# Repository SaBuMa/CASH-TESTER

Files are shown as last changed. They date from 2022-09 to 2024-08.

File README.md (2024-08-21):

# Proyecto Cash Tester

## Objetivos preliminares
* Implementar una solución viable a la problemática que más de 595.288 personas sufren en el país al no poder identificar eficazmente la denominación de las monedas de referencia __Colombiana.__ Desarrollando desde el campo de trabajo de la ingeniería una respuesta a una problemática latente, apostándole a la inclusión y al desarrollo del país.

* Implementar un sistema, con uso de la electrónica que generé una respuesta sonora, que una persona con baja visión/invidente reconozca a partir de la denominación de la moneda en vigencia.

## Descripción del Diseño
El proyecto se compone de un sensor (transductor) de resistencia sensible a la fuerza. La señal del transductor es acondicionada a través de un amplificador de instrumentación y un filtro pasa bajos.  
La señal proveniente del filtro es pasada por un detector de picos encargado de retardar el pico de voltaje el tiempo suficiente para que un circuito comparador la detecte, la clasifique y entregue un determinado voltaje DC al último circuito de la cadena que es un VCO (Voltage Controlled Oscillator).  
Por último, el VCO variará una alerta sonora en frecuencia para así de esta manera identificar el valor de la moneda.

## Descripción circuitos y Esquemáticos

* Un sensor (transductor) el cual es una resistencia sensible a la fuerza (FSR - FlexiForce A101).
* Circuito de acondicionamiento de señal usando un puente de wheatstone asi como también un amplificador de instrumentación y un filtro pasa bajos.

### Esquemático Circuito Amplificador y Circuito de filtrado

<p align="center">
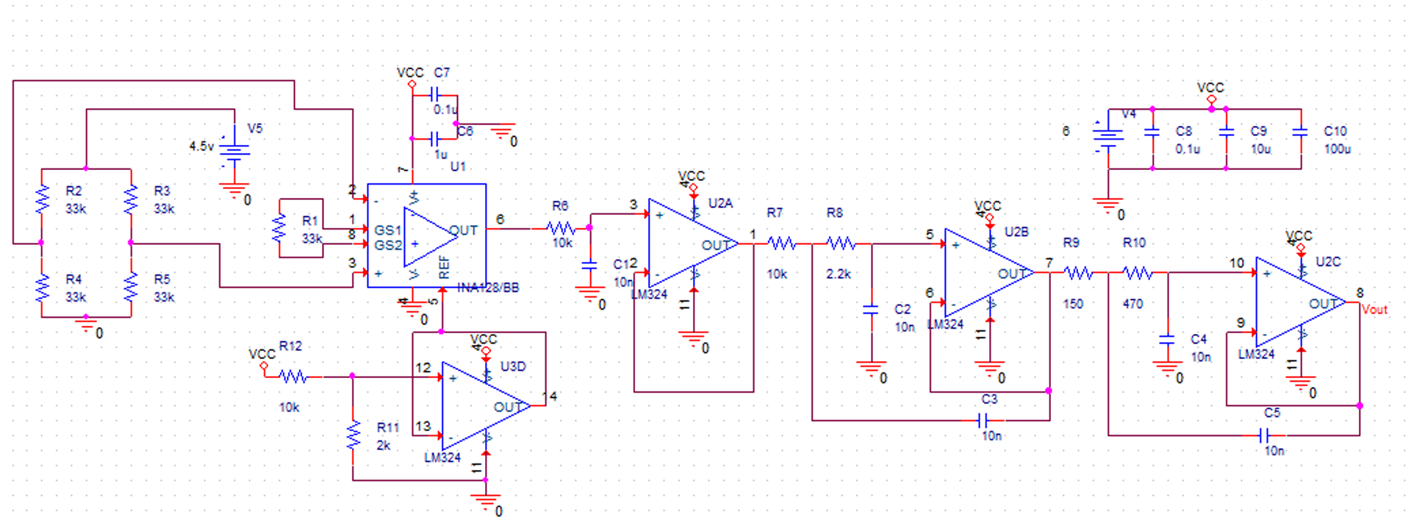
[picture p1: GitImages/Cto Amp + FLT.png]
Cto Amp + FLT
  
</p>

* La señal proveniente del filtro pasa bajos pasada por un circuito detector de picos el cual se encarga de retardar/ampliar la duración del pico de voltaje
* La señal proveniente del detector de picos es enviada a un comparador para clasificar y crear un voltaje DC.

### Esquemático Circuito Detector de picos y Circuito Comparador 
<p align="center">
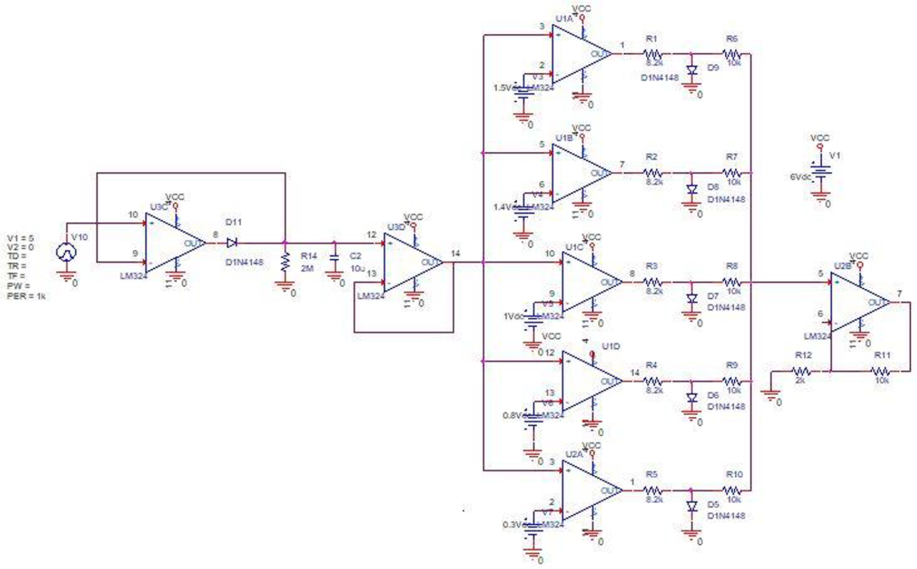
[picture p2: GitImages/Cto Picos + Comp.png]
Cto Picos + Comp
  
</p>

### Montaje en Protoboard para pruebas
<p align="center">
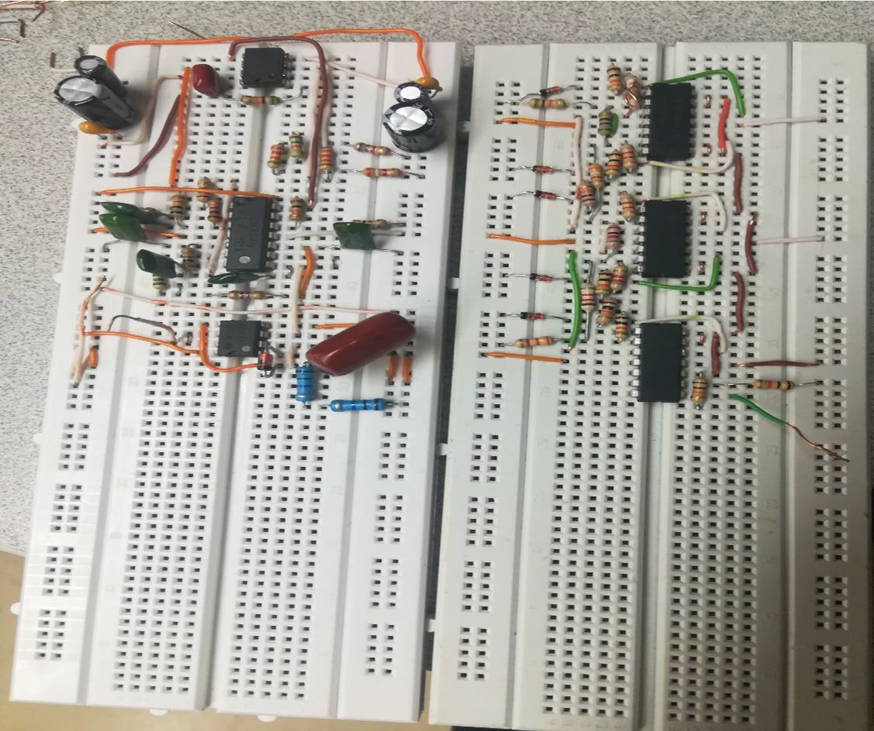
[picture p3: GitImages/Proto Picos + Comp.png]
Proto Picos + Comp
  
</p>

* El voltaje DC proveniente del comparador ingresa a un VCO el cual producirá una variación en frecuencia.  
* La frecuencia proveniente del VCO es usada para producir un sonido con el cual es posible identificar el valor de la moneda.

### PCB del Proyecto
<p align="center">
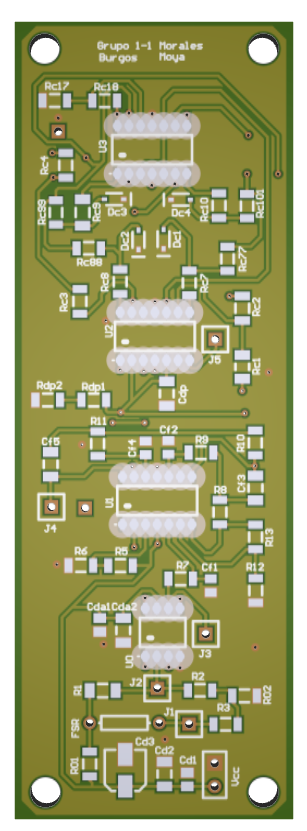
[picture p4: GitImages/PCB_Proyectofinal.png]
PCB_Proyectofinal
  
</p>

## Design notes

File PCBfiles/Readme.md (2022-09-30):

# En esta carpeta se encuentran los archivos de la pcb realizada en este proyecto

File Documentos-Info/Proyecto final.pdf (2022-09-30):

### DISEÑO FINAL: CASH TESTER

Andrea Camila Moya Buitrago
w.benavides@javeriana.edu.co

Natalia Morales Varón
nataliamorales@javeriana.edu.co

Santiago Burgos Martinez
santiagoburgos@javeriana.edu.co

Pontificia Universidad Javeriana

Bogotá, Colombia

INTRODUCCIÓN

En el presente informe del diseño final (cash tester), se analizará con detalle el proceso de concepción, diseño y construcción del proyecto que se llevó a cabo en la asignatura de fundamentos de diseño.

PALABRAS CLAVE

Amplificador instrumental, filtro pasa bajos, puente de Wheatstone, detector de picos, comparador, frecuencia, buzzer, invidentes.

OBJETIVO GENERAL

- Implementar una solución viable a la problemática que más de 595.288 personas sufren en el país al no poder identificar eficazmente la denominación de las monedas de referencia colombiana.

OBJETIVOS ESPECIFICOS

- Desarrollar desde el campo de trabajo de la ingeniería una respuesta a una problemática latente, apostándole a la inclusión y al desarrollo del país.
- Implementar un sistema, con uso de la electrónica que generé una respuesta sonora, que una persona con baja visión/invidente reconozca a partir de la denominación de la moneda en vigencia.

EQUIPO REQUERIDO

En la realización de la práctica se utilizaron los siguientes equipos:

- Generador de funciones - KEYSIGHT-33500

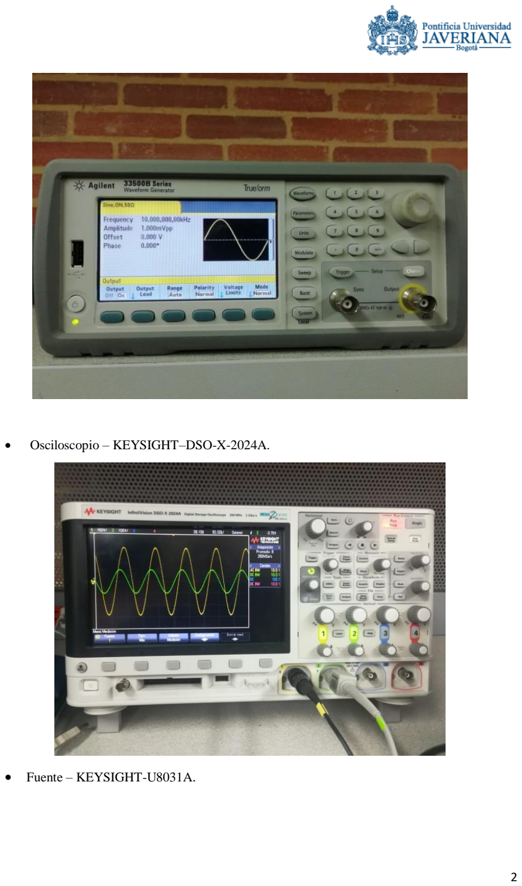
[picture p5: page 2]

- Osciloscopio – KEYSIGHT–DSO-X-2024A.
- Fuente – KEYSIGHT-U8031A.

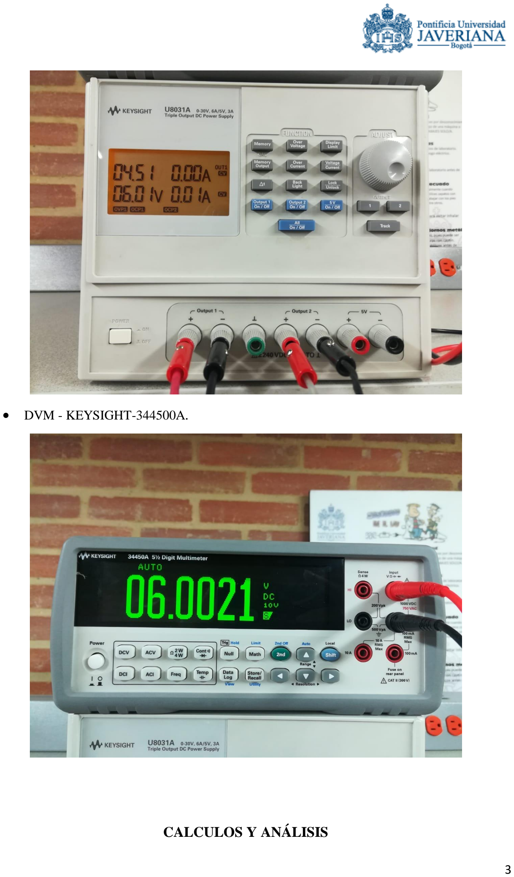
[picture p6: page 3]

- DVM - KEYSIGHT-344500A.

CALCULOS Y ANÁLISIS

El diseño se compone de un sensor (transductor) el cual es una resistencia sensible a la fuerza. Luego tenemos un acondicionamiento de señal que se compone de un amplificador de instrumentación y por un filtro pasa bajos, posteriormente la señal que sale del filtro es pasada por un detector de picos el cual se encarga de retardar el pico de voltaje lo necesario para que el comparador la detecte, la clasifique y entregue determinado voltaje DC al VCO que variará la frecuencia de un sonido para de esta manera identificar el valor de la moneda.

- Resistencia sensible a la fuerza (FSR)

FlexiForce A101

Para la realización de la practica utilizamos un sensor piezoeléctrico de fuerza ya que tiene un intervalo de medición de fuerza bastante grande y su diseño hace que sea cómodo para la idea principal que es la portabilidad.

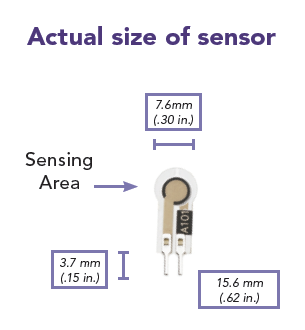
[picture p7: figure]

Fig 1. Sensor FlexiForce A101 y dimensiones

- Puente de Wheatstone

El puente de Wheatstone dentro de nuestro diseño cumple una función primordial ya que, de acuerdo con las especificaciones de nuestro sensor FSR (Force -Sensitive Resistor) escogido, este solo entrega una señal DC. De esta forma con la ayuda del puente de Wheatstone podemos obtener una señal diferencial la cual ya es posible que funcione de entrada a nuestro amplificador instrumental.

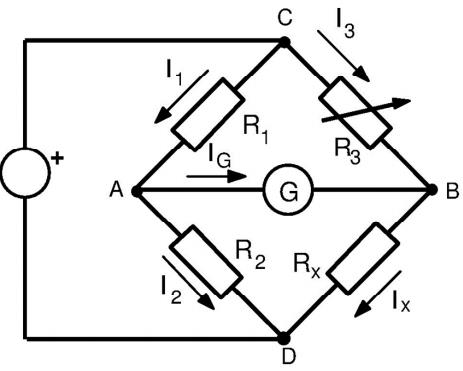
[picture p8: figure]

Fig2. Principio de funcionamiento de puente de Wheatstone. [1]

En efecto, cuando el puente está equilibrado sucede lo siguiente:

Ig = 0;I1 = I2;I3 = Ix; VA = VB

VCA

VAD

=

I1R1
I2R2

=

R1
R2

;

VCB

VBD

=

I3R3
IxRx

=

R3
Rx

VA = VB →

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
Luego, se obtiene que:

Rx = R3

R2
R1

Se puede demostrar que si se tiene un puente de Wheatstone equilibrado (IG = 0)

R1 = R2 = R3 = RX = R0.

Para determinar el valor de las resistencias del puente de Wheatstone que acompañan a nuestro sensor, partimos del datasheet de donde obtenemos la Fig 3. la cual nos dice que cuando el sensor no tiene fuerza aplicada sobre él, su resistencia máxima es de aproximadamente 32 KΩ.

Teniendo en cuenta esta resistencia máxima del sensor procedemos a buscar los valores comerciales de resistencias que se aproximen más a este valor para usarlas en el puente de Wheatstone. De la

búsqueda realizada encontramos que el valor más cercano a la resistencia del sensor es una resistencia de 33KΩ.

Por último, para la realización de simulaciones se opta por un valor base de 33k para el sensor dentro de nuestro puente de Wheatstone.

Fig 3. Grafica de Resistencia VS Presión (Fuerza) del sensor FlexiForce A101

ETAPA DE AMPLIFICACIÓN

- Amplificador de Instrumentación.

El amplificador de instrumentación tiene varias ventajas, una ganancia estable, lineal y seleccionable. Impedancia de entrada alta y una entrada diferencial con CMRR alto.

El esquemático en el cual está basado el amplificador instrumental es el siguiente

Fig 4. Esquemático amplificador instrumentación.

Etapa de pre-amplificación

Análisis

En el punto A:
VA − V1
RA

=

V1 − V2
RG

Despejamos VA

VA = V1 (

RA
RG

+ 1) −

RA
RG

V2

Ahora en el punto B:
V1 − V2
RG

=

V2 − VB
RB

Despejando VB

VB = V2 (

RB
RG

+ 1) −

RB
RG

V1

Si restamos ambas expresiones obtenemos

Vout = (V2 − V1

) (1 +
RA + RB
Rg

)

Nuestro paréntesis representa la ganancia diferencial de la etapa pre-amplificadora.

Etapa diferencial

Vout = (−

R2
R1

) VA (1 +

R2
R1

) ∗ (

R4
R3 + R4

) VB

TOTAL

Vd = VB − VA

Vcm =

VA + VB
2

Vout = −Vd [
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
)] + Vcm ∗ [
1 −

R2R3
R1R4

1 +

R3
R4

]

De donde se puede deducir lo siguiente

CMRR es cero sí 1 −

R2R3
R1R4

= 0. Esto si R2
R1

=

R4
R3

Además, se puede simplificar la ecuación si RA = RB

Ad =

R2
R1

(1 + 2
RA
Rg

)

La resistencia Rg permite variar la ganancia sin afectar el CMRR

Ahora, si nuestro terminal de Vref no se encuentra conectado a tierra, sino a otra tensión de referencia obtenemos entonces

Vout = Ad

(V

+ − V

−) + Vref

Por lo tanto:

Para la amplificación se tuvieron en cuenta dos amplificadores y se realizó una breve comparación con el fin escoger el más conveniente.

Amplificado r | Ganancia | CMRR | PSRR | Impedancia entrada | Impedanci a salida | BW | Slew Rate
LM324 | 100 V/mV | 70 típico | 100 típico | 12M | 58.3 | 1 MHz | 0.5 V/us
LM358 | 100 V/mV | 85 típico | 100 típico | 12 M | 58.3 | 1 MHz | 0.3 V/us

Tabla 1. Comparación entre amplificadores.

Observando la tabla podemos ver la diferencia existente en el CMRR y el slew rate. Teniendo en cuenta esta información obtenida de las hojas de especificaciones se puede deducir que el mejor LM358 es un mejor amplificador para esta aplicación.

De acuerdo a los requerimientos de la práctica, tenemos que sustituir los amplificadores previamente comparados por un amplificador de instrumentación. Ahora los requerimientos que tenemos para nuestro diseño son: un voltaje offset bajo tanto de entrada como de salida, un CMRR alto, la posibilidad de ser polarizado de forma single supply, tener una salida Rail to Rail.

Realizando una búsqueda intensiva de amplificadores de instrumentación en la página web de Texas Instruments (http://www.ti.com/amplifier-circuit/instrumentation/overview.html) buscando aquellos que cumplieran la mayoría de nuestros requisitos, como también estuvieran disponibles en el mercado colombiano reducimos nuestro resultado al amplificador de instrumentación INA 128, el cual a pesar de no poder cumplir nuestro requerimiento de Rail to Rail, obtenemos a cambio su disponibilidad en el mercado colombiano.

Amplificador Instrumental | Offset Voltaje | CMRR | Power supply | Rango de voltaje en la salida
INA 128 | 50 µV Max | 120 dB min | ±18 V Max | (V+) – 1.4 min

Tabla 2. Características por las cuales se escogió el INA128.

Teniendo la facilidad de la utilización de un Amplificador Instrumental como lo son los INA, procedimos a realizar los siguientes cálculos con el INA 128.

Para nuestros cálculos de la amplificación teniendo en cuenta la teoría nos basamos en el siguiente esquemático obtenido de la hoja de especificaciones.

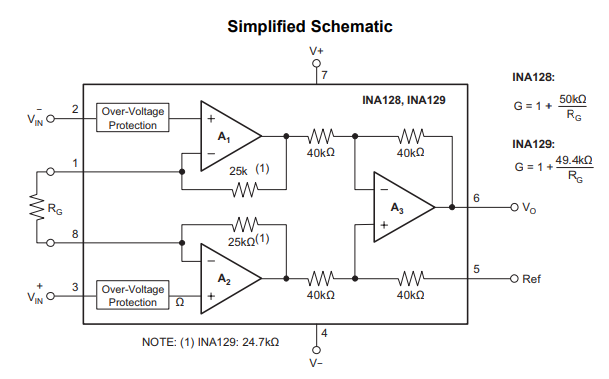
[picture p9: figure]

Fig 5. Esquemático INA 128.

Para determinar la ganancia que debería tener nuestro amplificador de instrumentación procedimos a realizar pruebas repetitivas (caracterización) con nuestro sensor para determinar el voltaje máximo que obtendremos de este. (anexo1)

De esta forma procedemos a calcular la ganancia teniendo en cuenta los voltajes de entrada, su voltaje máximo de salida, y su voltaje de referencia

(v

+ − v

### −)G + vref = vout

vout = vpolarizacion − vrango salida → vout = 6v − 0.9 → vout = 5.1v

v

+ = 3.81v

v

− = 2.25v

### vref = 1v

Despejando G de la ecuación obtenemos que

G = 2.63

Ahora procedemos a calcular la resistencia RG para obtener dicha ganancia. Para esto hacemos uso de la ecuación proporcionada por el datasheet del amplificador para el cálculo de G

G = 1 +

50k
Rg

En donde reemplazamos G por su valor previamente encontrado y procedemos a despejar Rg, de lo cual obtenemos que

### Rg = 30.67 KΩ

Con el valor de Rg encontrado procedemos a realizar la búsqueda de la resistencia teniendo en cuenta los valores comerciales. De la búsqueda realizada obtenemos que la resistencia más cercana es de 33KΩ.

Por último, habiendo obtenido la resistencia Rg = 33KΩ procedemos a recalcular tanto G como vout .

G = 1 +

50k
33k

= 2.52

Para hallar el vout máximo que obtendremos a la salida, resolvemos la ecuación

(v

+ − v

### −)G + vref = vout

### vout = 4.93v

Ahora sabemos que con nuestra moneda de mayor masa (1000= 9.7g) obtendremos un voltaje a la salida de nuestro amplificador instrumental máximo de 4.93v, que se encuentra dentro del rango aceptable especificado por el datasheet del componente.

ETAPA DE FILTRADO

- Filtro pasa bajos

Fig 6. aplicación filtro pasa bajos. [2]

Los filtros pasa-bajos son aquellos que introducen muy poca atenuación a las señales que son menores que una determinada frecuencia, está siendo la frecuencia de corte. Las frecuencias que son mayores que la de corte son atenuadas fuertemente.

En el caso más sencillo de implementación se tiene la siguiente configuración:

Fig 7. Filtro pasa-bajos simple/pasivo.[3]

El funcionamiento en el cual se basa un pasa bajos es en que el condensador presentará una gran oposición al paso de corrientes debidas a frecuencias bajas (https://www.ecured.cu/index.php?title=Frecuencias_bajas&action=edit&redlink=1) y como forma un divisor de tensión (https://www.ecured.cu/Divisor_de_tensi%C3%B3n) con la resistencia (https://www.ecured.cu/Resistencia) (en el dominio de frecuencia), aparecerá sobre él casi toda la tensión de entrada. Para frecuencias altas (https://www.ecured.cu/index.php?title=Frecuencias_altas&action=edit&redlink=1) el condensador presentará poca oposición al paso de la corriente y la resistencia se quedará con aproximadamente el total de la tensión de entrada, apareciendo muy poca tensión en extremos del condensador.

Una vez obtenida la etapa de amplificación se obtuvo un mejor y más trabajable pico de voltaje. En el dominio de la frecuencia Fig 23 se observó que la frecuencia fundamental, es decir la que nos interesa está en aproximadamente 2KHz, esta frecuencia equivale a la obtenida por la moneda de 1000. Para evitar que rebotes de la moneda u otras señales parasitas intervinieran en nuestro circuito se diseñó un filtro pasa bajas activo, debido a que fue el que mejor se acomoda a los requerimientos del sistema, con una frecuencia de corte de

5KHz (esto es porque la otra frecuencia-armónico está alrededor de 15KHz).para el diseño del filtro se usó la herramienta de “filter pro” de Texas instrument la cual planteó un filtro de quinto orden para tener una pendiente de caída mayor y por lo tanto un filtrado más eficiente.

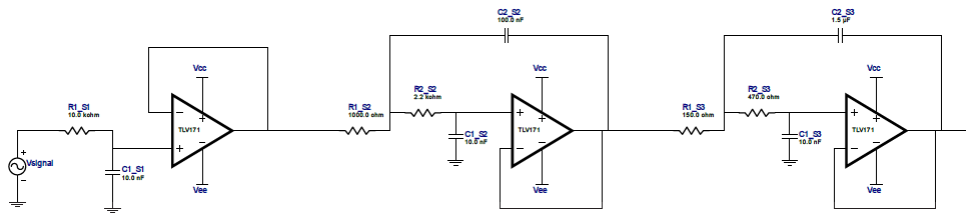
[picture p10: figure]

Fig 8. Filtro del circuito

Los circuitos integrados que se usaron en la práctica fueron diversos debido a que estábamos sujetos a la disponibilidad, por lo tanto, en la protoboard se usó el circuito integrado LM324 y en PCB se usó el TLV3544, pero se adquirieron estos circuitos integrados con el objetivo de que cumplieran la misma o similar función del TLV171 para que no representara una diferencia muy significativa.

Obteniendo el filtro se procedió a verificar por medio de las gráficas más relevante su correcta funcionalidad para verificar si es el modelo óptimo para la aplicación.

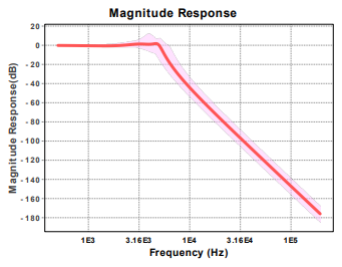
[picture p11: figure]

Fig 9. Respuesta de la magnitud del filtro pasa bajas.

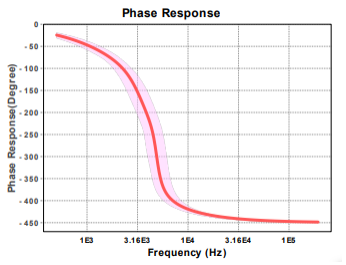
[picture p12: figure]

Fig 10. Respuesta en fase del filtro pasa bajas.

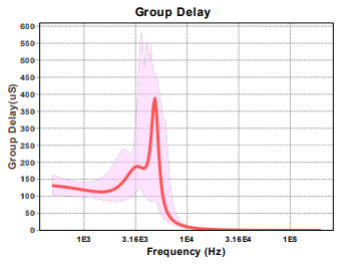
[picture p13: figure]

Fig 11. Delay del filtro pasa bajas.

Por lo tanto, se tienen las siguientes especificaciones:

Tipo de filtro | Pasa bajos
Tipo de respuesta del filtro | Chebyshev
Orden del filtro | 5.0
Topología del circuito | Un solo polo
Número de estados | 3.0

Frecuencia de la pasa banda | 5.0kHz
ganancia | 1
SingleSupply | 5
Tolerancia de las resistencias | E6
Tolerancia de los capacitores | E6
Tala 3. Especificaciones del filtro.

ETAPA DE DETECCIÓN DE PICOS

Para la etapa de detección de picos se usó una topología brindada por el profesor Helio Forero en la asignatura de núcleo fundamental electrónica analógica, el cual corresponde al siguiente esquemático.

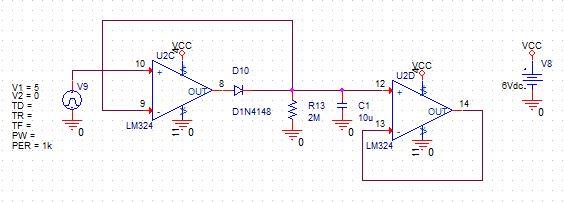
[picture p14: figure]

Fig. 12 Detector de picos.

En donde lo que sucederá es que el capacitor se va cargar al voltaje del pico detectado, posteriormente se agrega una resistencia en paralelo para controlar el tiempo de descarga del capacitor, obteniendo un τ (tao) de 5 mili segundos el cual nos da una idea aproximada del tiempo de descarga del capacitor.

ETAPA DE COMPARACIÓN

Para poder identificar la denominación de cada moneda se implementó la siguiente topología, la cual consta de 5 comparadores que al final llegan a un sumador.

Cada comparador funciona con un voltaje de comparación el cual está conectado a la terminal inversora del amplificador operacional, si el voltaje de la entrada del comparador (es decir, a la salida del detector de picos) es mayor o igual que este voltaje se encenderá y prendera un diodo, por lo tanto, la salida va a ser este voltaje, que usualmente oscila entre 0.56V a 0.62V

(valores reales). Al sumador le entraran los voltajes de la salida de cada comparador y las sumará, saliendo un voltaje distinto para cada moneda.

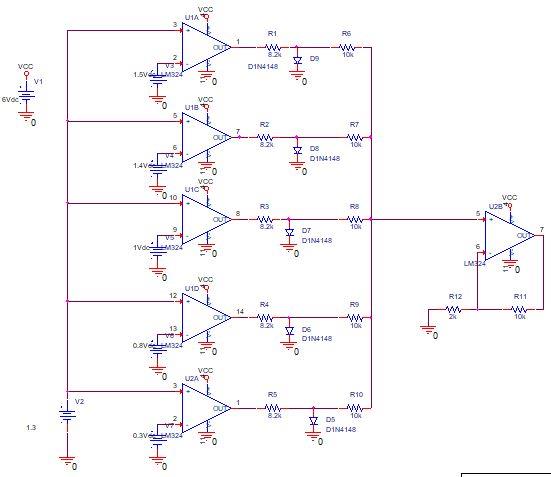
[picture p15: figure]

Fig. 13 Comparador

Para los voltajes de comparación es poco viable tener una fuente para cada voltaje, por lo tanto, se implementaron 5 divisores de voltaje.

PROCEDIMIENTO

Inicialmente la práctica se desarrolló en torno al análisis de la señal que proporciona el sensor de presión (FSR), por lo tanto, para obtener una salida diferencial se utilizó el puente de Wheatstone, una vez obtenida la salida diferencial requerida se inició con la etapa de amplificación y posteriormente con la etapa de filtrado, una vez obtenida la señal de entrada tratada se paso por un detentor de picos, el cual se encarga de retardar el voltaje pico y con ese voltaje DC se procede a compararlo para identificar la denominación de la moneda y esta señal se manifiesta de manera sonora a través de la variación de la frecuencia de sonido determinado.

En las imágenes siguientes se evidencia la implementación de nuestro diseño.

Para la realización de la practica implementamos todos nuestros cálculos teóricos y los esquemáticos propuestos.

Inicialmente la práctica se desarrolló en torno al análisis de la señal que proporciona el sensor de presión (FSR), por lo tanto, para obtener una salida diferencial se utilizó el puente de Wheatstone, una vez obtenida la salida diferencial requerida se inició con la etapa de amplificación, filtrado, detector de picos, comparador y por ultimo variación de la frecuencia de un buzzer.

Etapa de amplificación

Para la desarrollar la etapa de amplificación, primero se obtuvo por medio de medidas repetitivas un pico de voltaje que fue de aproximadamente 1.8 V por lo tanto se requería una amplificación de aproximadamente 2.5 voltios para obtener un pico de mayor, más visible y cercano a el mismo voltaje de polarización (6 - 0) sin sobrepasarlo.

Etapa de filtrado

Una vez obtenida la etapa de amplificación se obtuvo un mejor y más trabajable pico de voltaje, en el dominio de la frecuencia se observó que la frecuencia fundamental, es decir la que nos interesa está en aproximadamente 2KHz, para evitar que rebotes de la moneda u otras señales parasitas intervinieran en nuestro circuito se diseñó un circuito pasa bajas, debido a que fue el que mejor se acomoda a los requerimientos del sistema, con una frecuencia de corte de 5KHz (debido a que la otra frecuencia está alrededor de 15KHz), se desarrolló usando la herramienta de filter pro de Texas instrument y se planteó de sexto orden para tener una pendiente de caída más empinada y por lo tanto un filtrado más eficiente.

Fig. 14 Filtro del circuito

Los circuitos integrados que se usaron en la practica fueron diversos debido a que estábamos sujetos a la disponibilidad, por lo tanto en la protoboard se usó el circuito integrado LM324 y en PCB se usó el TLV3544, pero se adquirieron estos operacionales con el objetivo de que cumplieran la misma función del TLV171 por lo tanto esto representa una diferencia no muy significativa.

Detección de picos

Para la etapa de detección de picos se usó la siguiente topología comúnmente usada y funcionó de manera óptima sin necesidad de cambios relevantes, solo se adecuaron los valores de R y C para prolongar el tiempo en el cual el pico se mantiene constante.

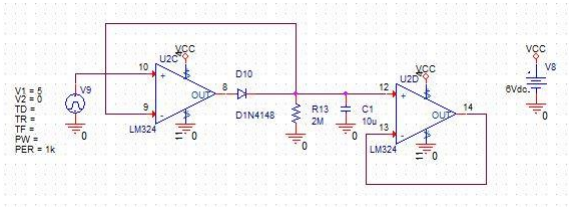
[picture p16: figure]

Fig. 15 Simulación detector de picos

La fórmula por la cual se calcularon los valores de R y C para hallar un valor de τ (tao) es la siguiente:
τ =

1
RC

= 5ms

Comparación

Para la etapa de comparación se diseñó una topología especial que cumpliera con los requerimientos del proyecto, debido, a que ninguna etapa previamente establecida era óptima.

El diseño se basó en el siguiente comparador, que se seleccionó básicamente por el poco espacio que usa y la facilidad de su implementación.

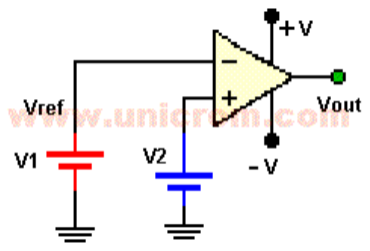
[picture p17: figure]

Fig. 16 topología básica de un comparador [8]

Lo cual tendrá a su salida:

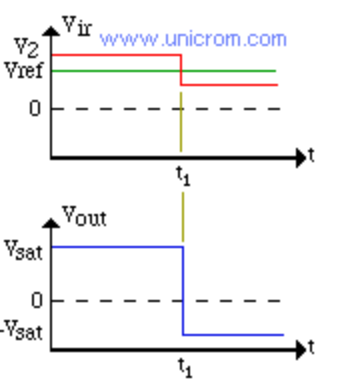
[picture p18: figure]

Fig. 17 Graficas de salida de un comparador básico. [8]

Luego se decidió agregar al diseño diodos para que si la comparación era igual o mayor se encendiera y por ende el comparador quedara a este voltaje y con la siguiente topología no inversora de un sumador obtener un voltaje distinto para cada moneda, debido a que para el pico de voltaje más grande todos los comparadores se van a encender, debido a que este voltaje es mayor que a todos los voltajes de comparación.

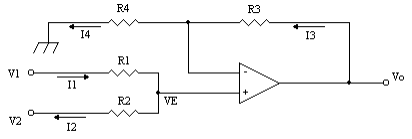
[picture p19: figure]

Fig. 18 Topología implementada de un sumador. [9]

En donde se adecuó el diseño para 5 entradas, debido a que todos los voltajes son similares (los del diodo) se usaron las mismas resistencias (10K ohms), para las resistencias de la entrada inversora del amplificador operacional y la salida (realimentación) se halló la función de transferencia y se reemplazó para una ganancia unitaria.

Para el análisis del sumador se efectuaron todos los cálculos necesarios para entender con profundidad el proceso que se lleva a cabo, para esto se hizo superposición para calcular el voltaje que teóricamente debería salir del sumador para cada moneda, siempre basándonos en la función de transferencia, la cual es la siguiente:

## v0 = vx ⋅ (1 +

Rf
R1

## ) vx = v1 + v2 + v3 + v4 + v5

En las cuales remplazamos v0
por el voltaje deseado cuando tenemos todos los diodos encendidos (se introduce la moneda de mayor denominación), el cual fue de 5 voltios.

Teniendo en cuenta que:

## 0.56 = v1 = v2 = v3 = v4 = v5

Remplazamos para hallar la relación entre las resistencias Rf y R1 la cual fue de aproximadamente de 8, por lo tanto, usamos Rf = 8.2kΩ y R1 = 1.2kΩ, cumpliendo así los requerimientos deseados.

Posteriormente apagamos uno por uno los diodos para calcular los voltajes DC que saldrían del sumador con cada entrada, teniendo en cuenta que cuando no se prende un comparador, a la entrada del sumador tenemos la resistencia de 10kΩ en serie con la resistencia de 8.2kΩ a tierra. Los voltajes a la salida del sumador teóricamente son:

Denominación de la moneda | Voltaje de salida (V)
1000 | 5
500 | 4.37
200 | 3.6
100 | 3.1
50 | 2.6
Tabla 4. Voltajes teóricos de salida del comparador con cada moneda

Implementando el circuito anteriormente descrito (Fig. 18) se obtuvo el esquematico de la figura 19, cumpliendo el objetivo de que con cada pico del voltaje saliera un valor DC a la salida del sumador.

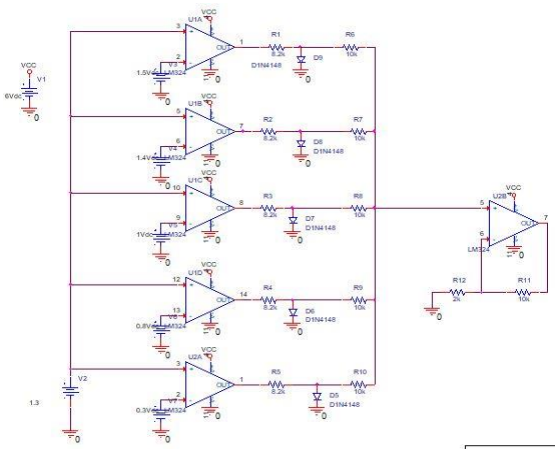
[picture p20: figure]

Fig. 19 simulación de la etapa de comparación

Por último, se implementó el detector de picos junto al comparador para verificar que sirviera de manera adecuada, el proceso fue exitoso y con esto se dio paso a la implementación física en la protoboard.

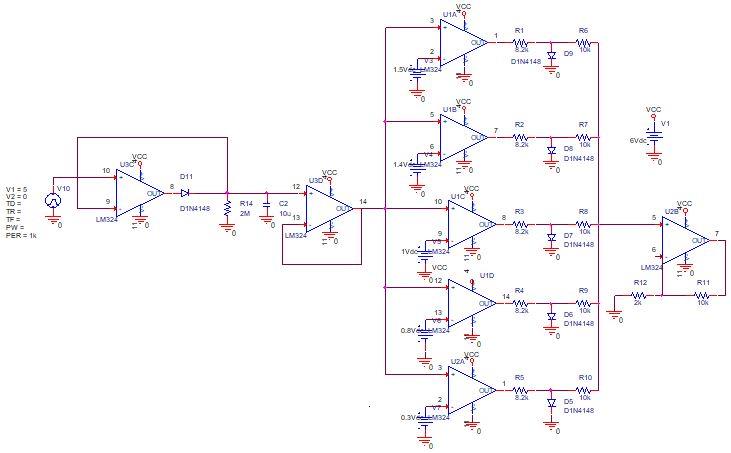
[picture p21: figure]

Fig. 20 Simulación etapa de detección de picos y etapa de comparación

Posteriormente se unieron las dos etapas comprobando la congruencia de los dos diseños y verificando que van acorde con los requerimientos del proyecto, lo cual se evidencio en la siguiente imagen que corresponde a la simulación de las dos etapas. Luego se implementó en protoboard y en PCB.

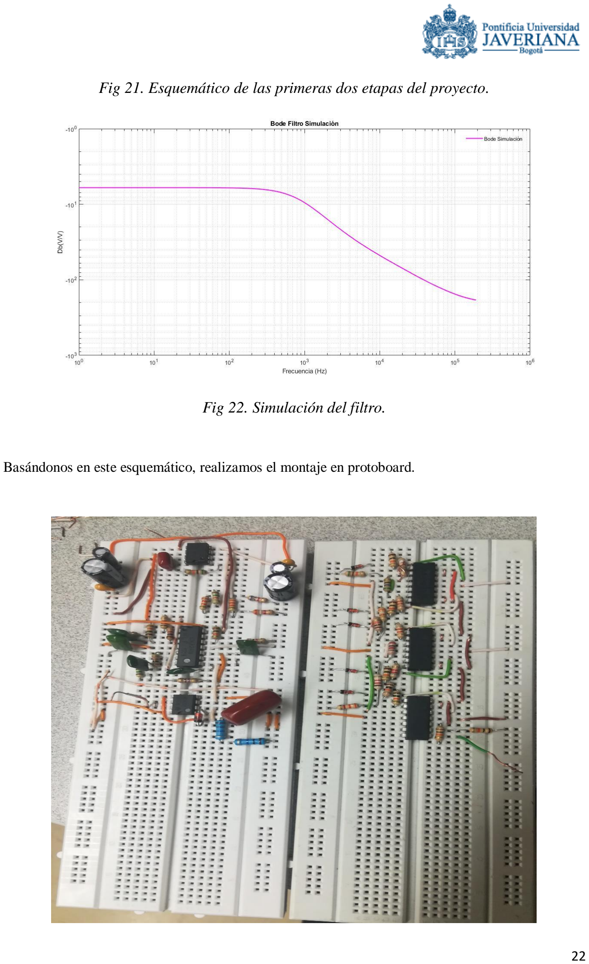
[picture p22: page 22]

Fig 21. Esquemático de las primeras dos etapas del proyecto.

Fig 22. Simulación del filtro.

Basándonos en este esquemático, realizamos el montaje en protoboard.

Fig 23. Montaje en protoboard.

ANÁLISIS DE RESULTADOS

- Ganancia.
La ganancia es una magnitud que expresa la relación entre amplitudes de señales de entrada con señales de salida. Su unidad es adimensional. (V/V)

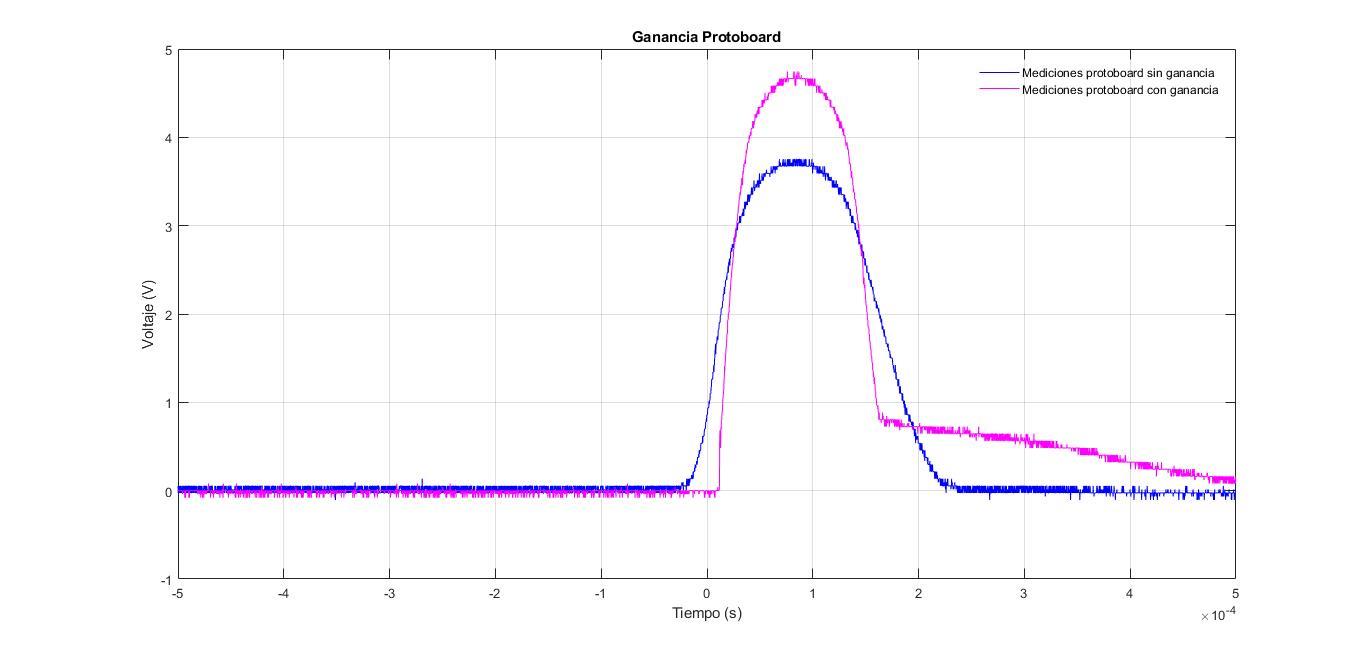
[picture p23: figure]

Fig 24. Ganancia protoboard.

De la gráfica de ganancia de protoboard podemos observar la señal que entra y sale de nuestro amplificador instrumental en donde comprobamos con las ecuaciones previamente descritas en el documento nuestros cálculos teóricos.

Al realizar la comparación entre las salidas de nuestro amplificador de instrumentación implementado tanto en protoboard como en PCB se puede ver que hay concordancia entre ellos, con la diferencia que los resultados obtenidos en PCB poseen menor ruido al final del pulso, lo cual se traduce en un mayor rango dinámico.

- Manejo

Para la realización del manejo de nuestro filtro, configuramos el generador de funciones para obtener una onda seno, con un offset de 2.5v. estos valores son en concordancia a los valores que obtendremos del INA128 en la práctica.

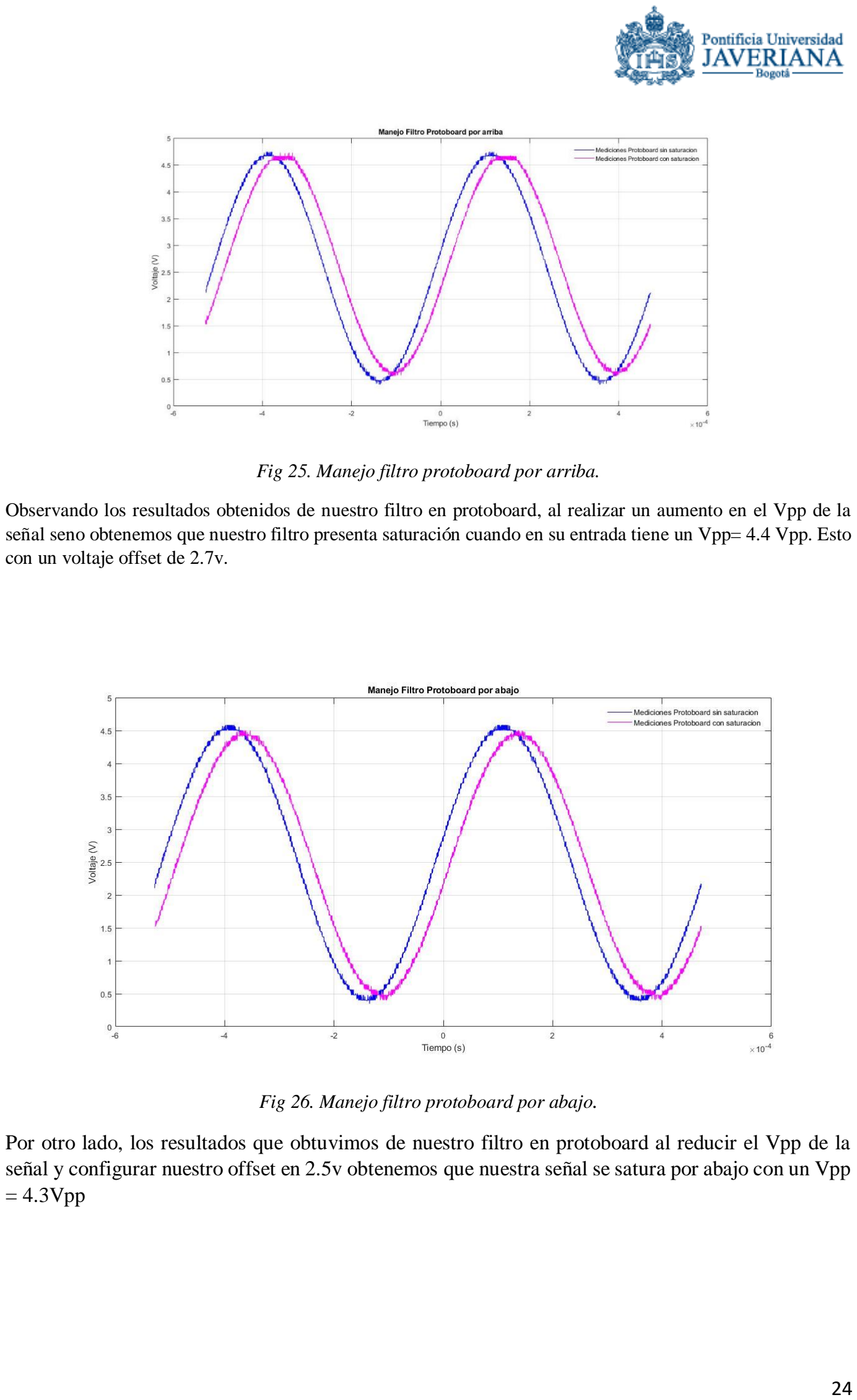
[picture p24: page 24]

Fig 25. Manejo filtro protoboard por arriba.

Observando los resultados obtenidos de nuestro filtro en protoboard, al realizar un aumento en el Vpp de la señal seno obtenemos que nuestro filtro presenta saturación cuando en su entrada tiene un Vpp= 4.4 Vpp. Esto con un voltaje offset de 2.7v.

Fig 26. Manejo filtro protoboard por abajo.

Por otro lado, los resultados que obtuvimos de nuestro filtro en protoboard al reducir el Vpp de la señal y configurar nuestro offset en 2.5v obtenemos que nuestra señal se satura por abajo con un Vpp = 4.3Vpp

- Factor de rechazo en modo común.

El factor de rechazo al modo común o CMRR, (Common Mode Rejection Ratio) es uno de los parámetros de un amplificador operacional (https://es.wikipedia.org/wiki/Amplificador_operacional)

Es un valor que principalmente mide lo bien que un amplificador operacional puede ignorar los voltajes que son comunes a ambas de sus entradas de corriente directa, describe cuan limpiamente este amplifica las señales que aparecen como diferencias de tensión en sus entradas.

El CMRR siempre es positivo y sus unidades son los decibelios. Mientras más alto se obtenga el CMRR mejor rechazo a ruido se obtendrá.

Este dado por la siguiente formula:
CMRR = 20 log10 (

Ad
As

)

En donde Ad es la ganancia en modo diferencial y As es la ganancia en modo común.

| CMRR (dB)
Protoboard | 46.64

Tabla 4. Datos obtenidos de CMRR.

- Factor de rechazo a fuentes

El Factor de Rechazo a Fuente de Alimentación o PSRR (Power Supply Rejection Ratio) es principalmente usado para describir la cantidad de ruido de una fuente que un dispositivo puede rechazar.

Es la capacidad de un amplificador para mantener su voltaje de salida a medida que varía la tensión de alimentación en DC. Relación entre el cambio en la alimentación a la tensión de entrada equivalente diferencial que se produce entre los terminales del operacional. Un amplificador operacional ideal tiene PSRR infinito.

Este se calcula con la siguiente formula

### PSRR = 20 log10 (

Δvfuente

Δvios

### ∗ Av) dB

En donde Δvfuente es la variación que se efectúa a la fuente y Δvios es la variación del voltaje de salida del circuito respecto a la variación del voltaje de entrada.

| PSRR
Protoboard | 55.91
Tabla 5. Datos obtenidos de PSRR

- Impedancia de entrada y de salida.
| Zin | Zout
Protoboard | 16.695k Ω | 1.6kΩ

Tabla 6. Datos obtenidos de las impedancias de los circuitos

- Ancho de banda.

El ancho de banda es la diferencia existente entre las frecuencias superior e inferior de varias frecuencias del sistema. Su medición está dada en hertz (Hz). Una de sus características principales es que cualquier banda de una anchura puede llevar bastante información independientemente donde se encuentre el espectro de frecuencia.

Para determinar el ancho de banda se definen dos frecuencias limites, estas deben corresponder a una amplitud aproximada de 0.7 de la amplitud de la señal.

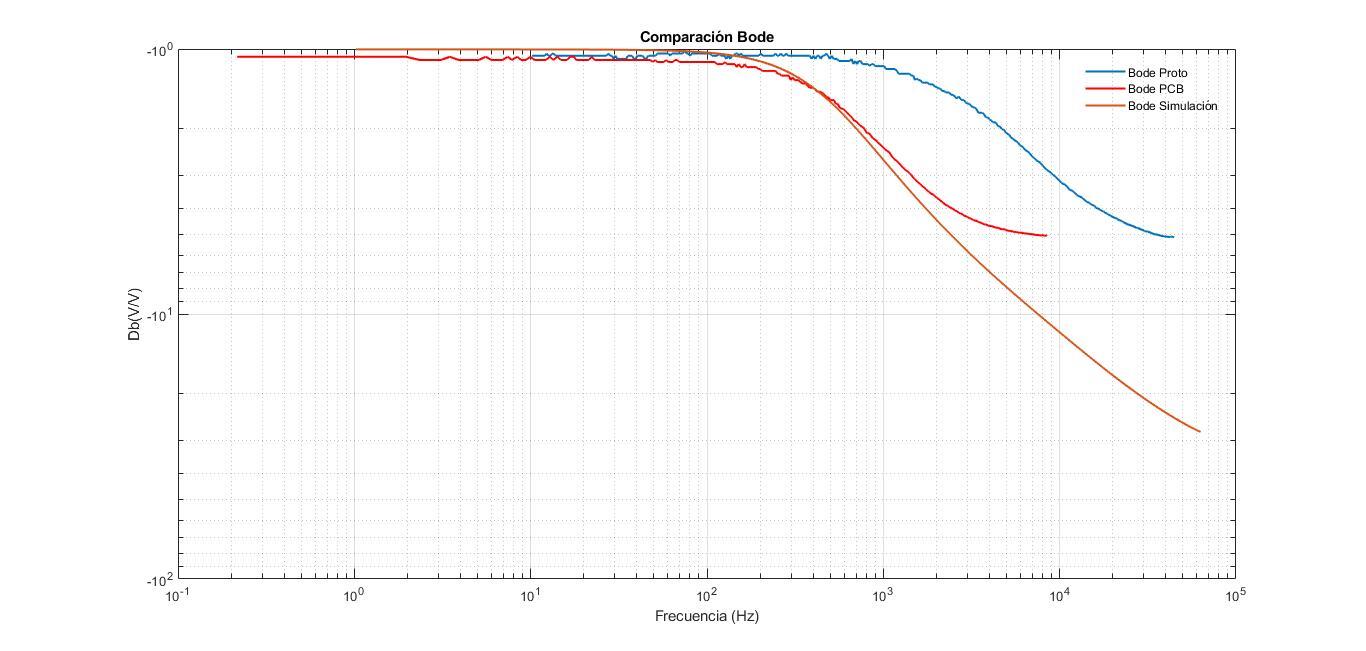
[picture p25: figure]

Fig 27. Comparación bode.

Basados sobre la definición del ancho de banda en el filtro pasa bajas que se diseñó con frecuencia de corte de aproximadamente 5KHz (es decir se introduce un polo en aproximadamente 5KHz), se puede observar que la frecuencia de corte del filtro es aproximadamente ese valor en donde el bode del circuito implementado en protoboard (gráfica de color azul) tiene una frecuencia de corte un poco más grande debido a que los condensadores usados no fueron de los valores exactos del diseño. En tanto las gráficas de la simulación (naranja) y el bode del PCB (rojo) tienen gran congruencia entre ellas.

- Rango dinámico

El rango dinámico es la diferencia existente entre el nivel más alto de la señal que se puede producir con un sistema y la frecuencia de mayor nivel que componga el piso de ruido.

Se define por el margen que existe entre un nivel de referencia del sistema y el ruido de fondo de este mismo. Su medición se realiza con la ayuda de la herramienta FFT (fast fourier transform).

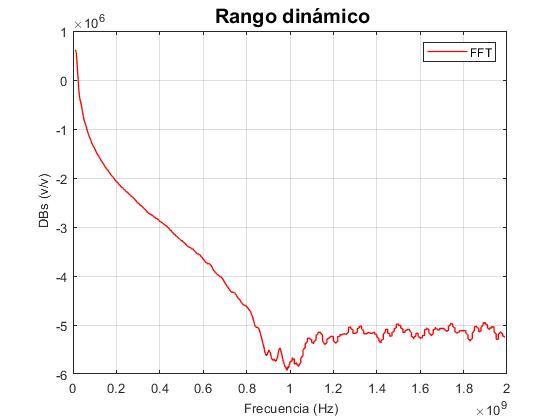
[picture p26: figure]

Fig 28. Gráfica de rango dinámico.

El rango dinámico del circuito completo del proyecto (cash tester) se puede analizar en la imagen anterior y su valor se puede aproximar a 57 dB.

- Potencia
Para calcular la potencia disipada del circuito se utilizó la siguiente formula:

P = v ⋅ I

Se procedió a medir la corriente que consume el circuito y se multiplico con el voltaje de alimentación brindándonos una potencia de 32.22mW.

- Piso de ruido

Relación señal a ruido se define como la relación de la potencia señal que se transmite y la potencia de ruido que la corrompe. Refiere a la diferencia en dB entre el nivel promedio de la señal y el nivel promedio del piso de ruido

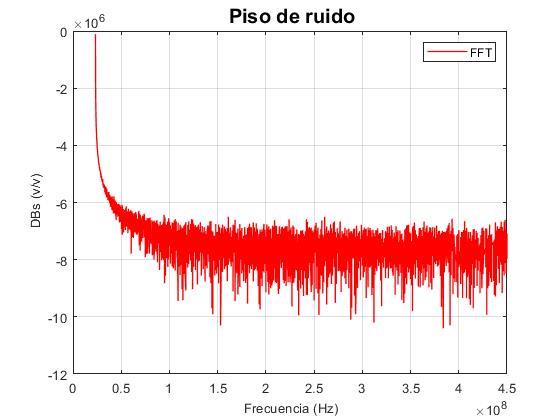
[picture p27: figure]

Fig 29. Gráfica piso de ruido

En la figura 29 de puede observar a escalas reales que el piso de ruido del proyecto completo en protoboard es aproximadamente 74dB.

CONCLUSIÓNES

- La ingeniería a parte de tener componente muy fuerte en cuanto al desarrollo tecnológico debe tener un componente humano y dar soluciones viables a problemáticas constantes que viven millones de personas.
- Teniendo en cuenta el rango dinámico obtenido en la protoboard y en la PCB universal, podemos ver que en PCB generalmente el rango dinámico es más alto debido a que el ruido que se encuentra en este sistema es menor, ya sea por los cables utilizados en montaje, los componentes utilizados (ya que en PCB se utilizan componentes para montaje superficial), entre otros.
- Es necesario tener en cuenta los parámetros necesarios para la escogencia de todos los elementos que se utilicen en el montaje y que además tengan todos aquellos requisitos que nuestro sistema requiere para que se pueda realizar satisfactoriamente, ya que cualquier cambio de nuestro sistema hace que se cambien nuestros cálculos y probablemente las señales obtenidas a la salida.
- Es importante verificar siempre en nuestros montajes el buen estado de la protoboard y de la PCB universal, puesto que esto puede llegar a afectar bastante algún resultado de medición de nuestro sistema.

REFERENCIAS

- Link datasheet INA128
http://www.ti.com/lit/ds/symlink/ina128.pdf
- Link Data sheet lm324
http://www.electronicoscaldas.com/datasheet/LM124-LM124A-LM224-LM224A-LM324-LM324A-LM2902-LM2902V-LM224K-LM224KA-LM324K-LM324KA-LM2902K-LM2902KV-LM2902KAV_TI.pdf (http://www.electronicoscaldas.com/datasheet/LM124-LM124A-LM224-LM224A-LM324-LM324A-LM2902-LM2902V-LM224K-LM224KA-LM324K-LM324KA-LM2902K-LM2902KV-LM2902KAV_TI.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)
- Link Datasheet lm358
http://www.electronicoscaldas.com/datasheet/LM158-LM158A-LM258-LM258A-LM358-LM358A-LM2904-LM2904V_TI.pdf (http://www.electronicoscaldas.com/datasheet/LM158-LM158A-LM258-LM258A-LM358-LM358A-LM2904-LM2904V_TI.pdf)
- [1] Rodríguez Pozueta, Miguel Angel “PUENTE DE WHEATSTONE” https://personales.unican.es/rodrigma/PDFs/Puente%20de%20Wheatstone.pdf
- [2] Learning about electronics http://www.learningaboutelectronics.com/Articles/Low-pass-filter.php
- [3] Filtro pasa bajos
https://www.ecured.cu/Filtro_pasa_bajos
- [4] CMRR
https://es.wikipedia.org/wiki/Rechazo_al_modo_com%C3%BAn
- PSRR
https://es.wikipedia.org/wiki/Factor_de_Rechazo_a_Fuente_de_Alimentaci%C3%B3n
- [6] Piso de ruido
http://azimadli.com/vibman-spanish/pisoderuido1.htm
- Ancho de banda
http://musiki.org.ar/Ancho_de_banda_(%CE%94f_)
- Rango dinámico y piso de ruido http://www.equaphon-university.net/rango-dinamico-y-relacion-senal-ruido/
- [7] AMPLIFICADOR SUMADOR NO INVERSOR https://www.electronicafacil.net/tutoriales/AMPLIFICADOR-SUMADOR-NO-INVERSOR.php
- [8] https://unicrom.com/comparador-con-amplificador-operacional/
- [9] https://www.electronicafacil.net/tutoriales/AMPLIFICADOR-SUMADOR-NO-INVERSOR.php (https://www.electronicafacil.net/tutoriales/AMPLIFICADOR-SUMADOR-NO-INVERSOR.php)

ANEXOS

### 1. Caracterización del sensor Flexiforce A101

### 2. Parámetros requeridos del INA 128

### 3. Especificaciones tenidas en cuenta para la Tabla 1

LM324

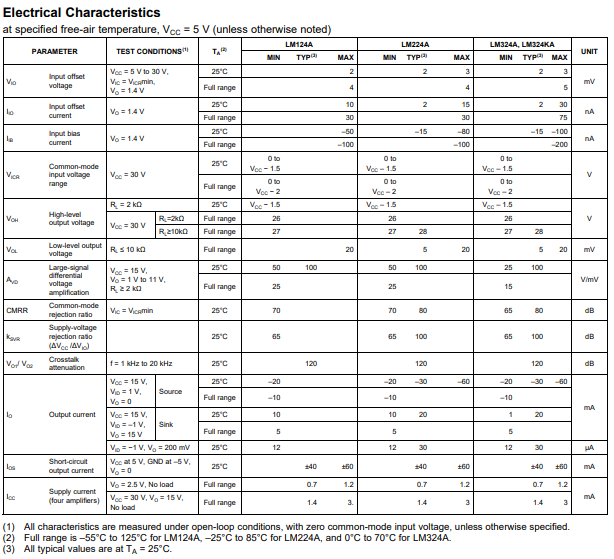
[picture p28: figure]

LM358
